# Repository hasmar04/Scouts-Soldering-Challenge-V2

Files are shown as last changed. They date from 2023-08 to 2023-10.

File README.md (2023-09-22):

# Scouts-Soldering-Challenge-V2

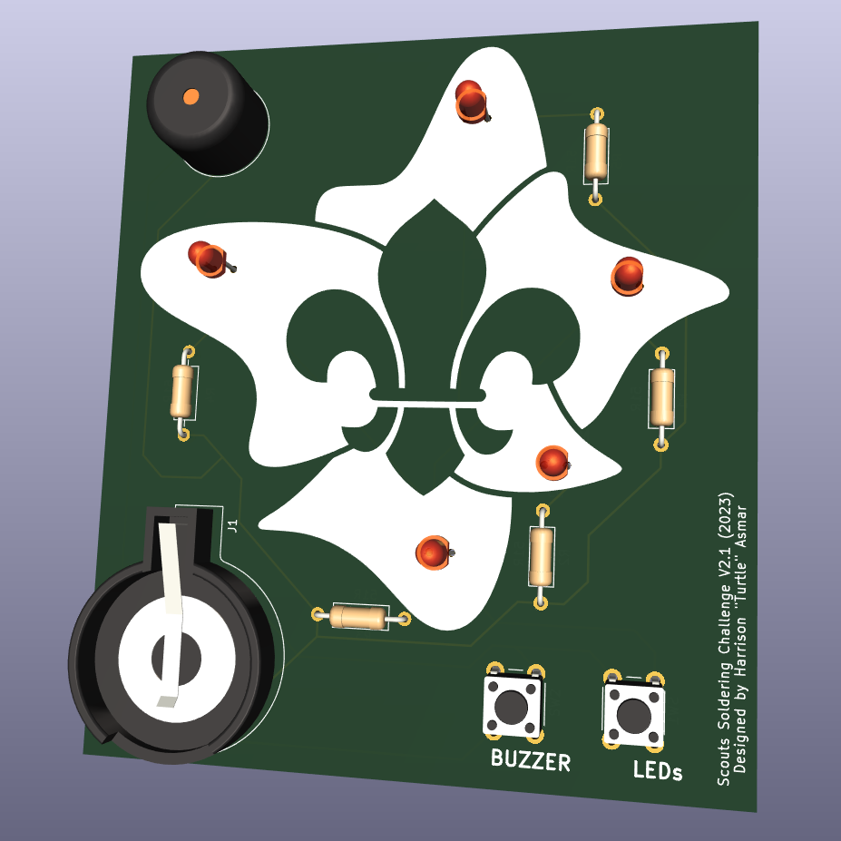
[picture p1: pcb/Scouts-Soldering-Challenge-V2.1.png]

 
A soldering challenge suitable for Scouts all the way to Rovers, without using an Arduino. 

As a member of the Australian Scouting movement, the logo has been used within this design for the purpose of promoting the movement, and to help the project to the target audience of Scouting members. 

For more information and/or assistance with implementing this challenge in your own Scout group, contact me at [246328@scoutsqld.com.au](mailto:246328@scoutsqld.com.au) 

### For more information on the Australian Scouting Movement, visit https://scouts.com.au/

## Components Required
- 1x PCB (see 'pcb' folder)
- 2x Red LED
- 1x Green LED
- 1x Yellow LED
- 1x Orange LED
- 5x 51 ohm resistor
- 1x 6x6mm push button
- 1x Buzzer
- 1x Battery Holder

More information can be found in the [Procurement Guide](/docs/Procurement%20Guide.md)

## Documentation
Documentation can be found in the [/docs](/docs) folder. This includes:
- Procurement Guide
- Assembly Guide

## Contributing
If there is anything that you think is missing from this repository, or you find an error, please [create an issue](</issues>) or fix it yourself and create a pull request.

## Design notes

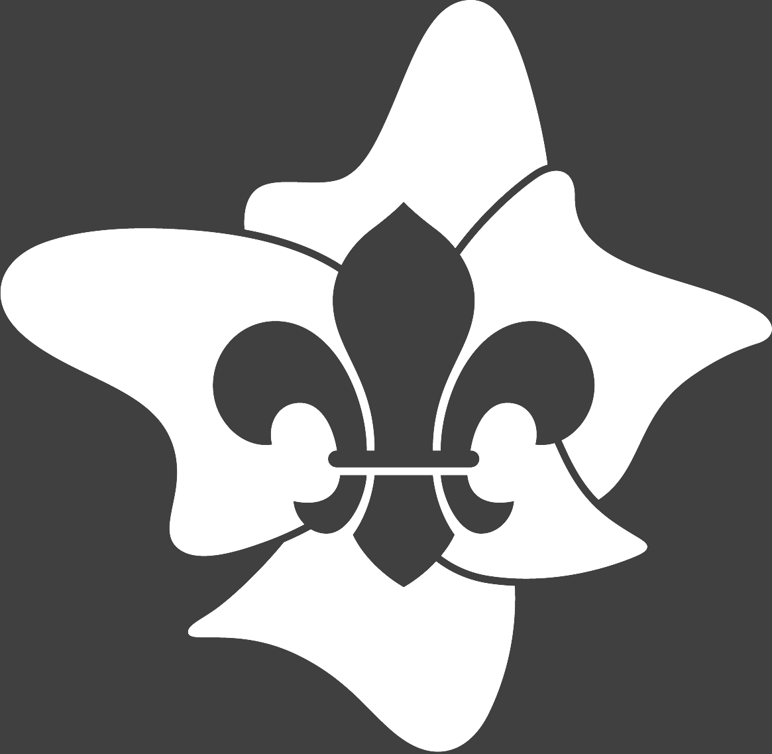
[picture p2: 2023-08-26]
Scouts Australia National White.png

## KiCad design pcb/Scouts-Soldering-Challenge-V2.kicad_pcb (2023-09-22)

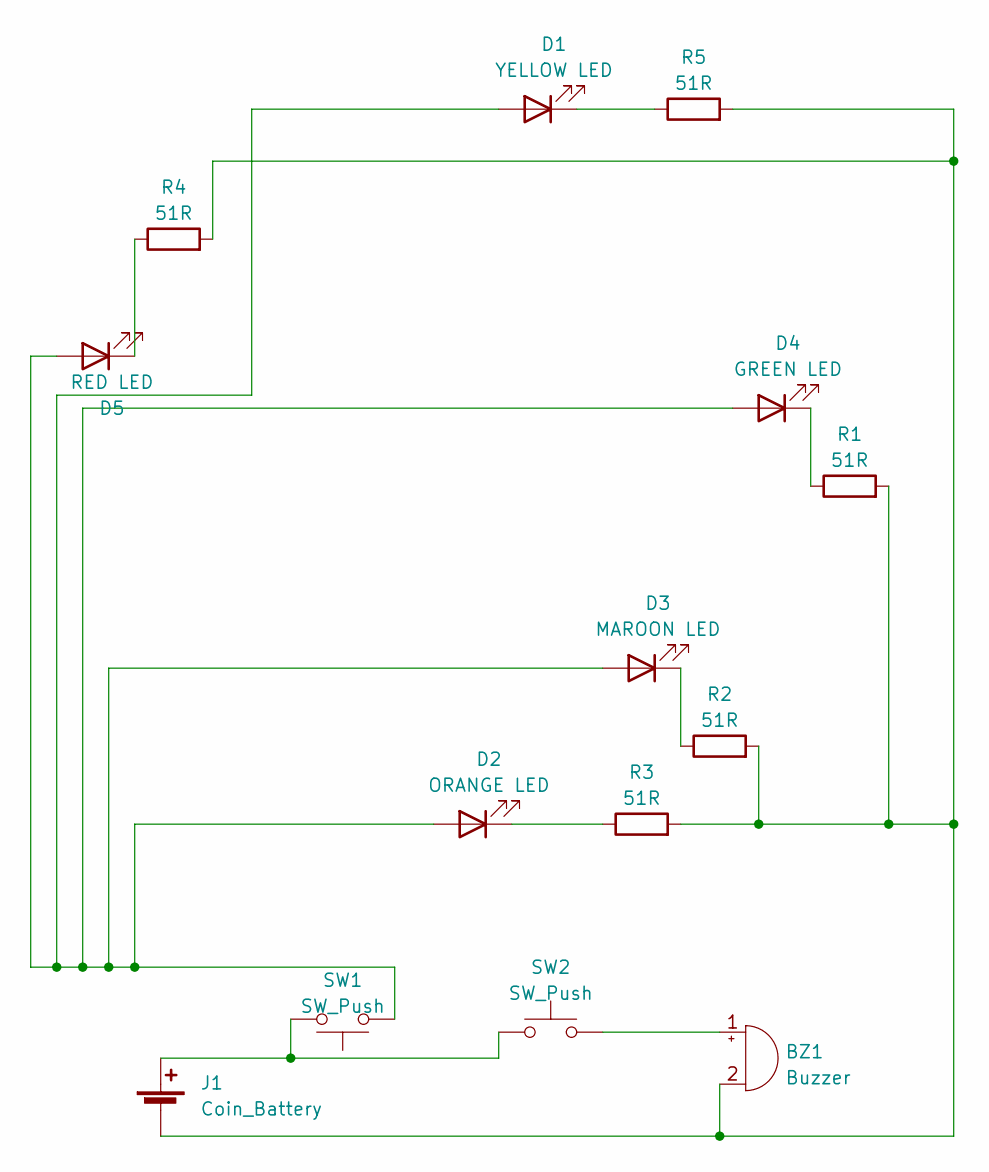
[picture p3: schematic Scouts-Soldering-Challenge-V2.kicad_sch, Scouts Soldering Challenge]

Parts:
BZ1: Buzzer; Buzzer_TDK_PS1240P02BT_D12.2mm_H6.5mm
D1: YELLOW LED; LED_D3.0mm
D2: ORANGE LED; LED_D3.0mm
D3: MAROON LED; LED_D3.0mm
D4: GREEN LED; LED_D3.0mm
D5: RED LED; LED_D3.0mm
J1: Coin_Battery; BatteryHolder_Keystone_103_1x20mm
R1, R2, R3, R4, R5: 51R; R_Axial_DIN0207_L6.3mm_D2.5mm_P10.16mm_Horizontal
SW1, SW2: SW_Push; SW_PUSH_6mm

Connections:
unnamed: BZ1.2 (+), J1.2 (-), R1.2, R2.2, R3.2, R4.2, R5.2
unnamed: BZ1.1 (-), SW2.2
unnamed: D1.2 (A), D2.2 (A), D3.2 (A), D4.2 (A), D5.2 (A), SW1.1
unnamed: D1.1 (K), R5.1
unnamed: D2.1 (K), R3.1
unnamed: D3.1 (K), R2.1
unnamed: D4.1 (K), R1.1
unnamed: D5.1 (K), R4.1
unnamed: J1.1 (+), SW1.2, SW2.1

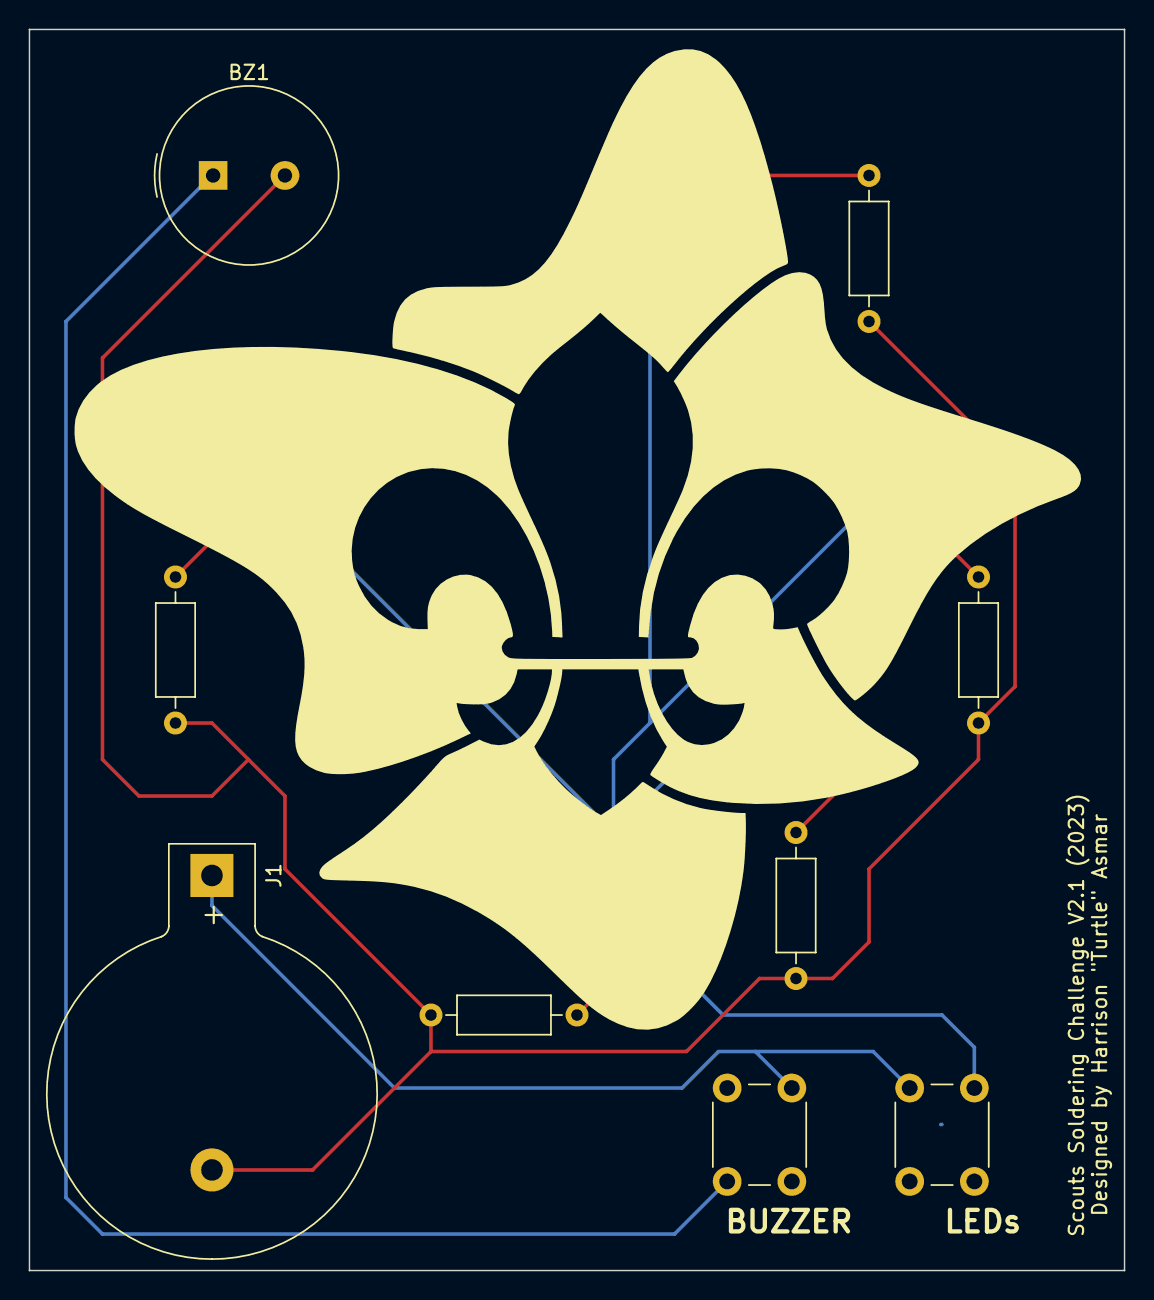
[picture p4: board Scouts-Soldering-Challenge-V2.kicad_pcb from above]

Board: 2 copper layers, 76.2 x 86.4 mm, 14 parts (0 on the bottom side), 9 nets.

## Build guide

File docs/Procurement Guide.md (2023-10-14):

 # Procurement Guide
For most people wanting to complete this project with a group, Element14 (au.element14.com) is the best place to acquire components from. They are based in Australia, and have pricing very similar to buying directly from suppliers overseas using a site such as Alibaba. 

Key characteristics that are needed when finding components:
- LEDs – through-hole, 3mm casing
- Push buttons – case dimensions of 6x6mm, 4 legs, through-hole, single-pole single-throw (SPST)
- Buzzer - Ensure the buzzer supports 3V, and the legs are 5mm (or close to) apart. Also ensure the buzzer you choose contains all the circuitry required to buzz, and does not need an external circuit. 
- Resistors – resistance of 51ohm, through-hole. Does not need to be more than 500mW or have a resistance tolerance of less than 1-2%. 
- Battery Holder - Make sure the diameter of the holder is 20mm if you want to use CR2032 or CR2025 batteries (both very common) and that the two legs on the holder are 20mm apart. Also, ensure the batteries you are using, if different to the ones listed, output 3V. 

Below is a list of parts that were available at the time of writing that would be suitable for this project:
- 3mm Red LED - https://au.element14.com/kingbright/l-1334surtk/led-3mm-red-630nm-red-transparent/dp/4062027
- 3mm Green LED - https://au.element14.com/multicomp/703-0087/led-green-3mm-572nm-standard/dp/2112096 
- 3mm Orange LED - https://au.element14.com/multicomp/mcl034at/led-3mm-32-orange/dp/1581126 
- 3mm Yellow LED - https://au.element14.com/lumex/ssl-lx3044yc/led-3mm-yellow-90mcd-585nm/dp/7605560 
- 6x6mm push button - https://au.element14.com/apem/mjtp1230/switch-tactile-spst-50ma-through/dp/4511189 
- Buzzer - https://www.jaycar.com.au/mini-piezo-buzzer-3-16vdc/p/AB3462
- 51ohm resistor - https://au.element14.com/multicomp-pro/mp006873/res-51r-0-25w-axial-metal-film/dp/3650040
- Battery Holder - https://au.element14.com/keystone/1066/battery-holder-1way/dp/133983901

If these parts are not available, there should be similar components available. Element14 also has the option to search for similar products based of characteristics like size and colour.

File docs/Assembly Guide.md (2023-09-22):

# Assembly Guide
## Before Proceeding
Ensure that you have all components listed in the [Procurement Guide](https://github.com/hasmar04/Scouts-Soldering-Challenge-V2/blob/main/docs/Procurement%20Guide.md), as well as a soldering iron and some solder. Lead-free solder is recommended, although it does require a higher temperature on the soldering iron. 
## Step 1: Sort Components Into Sets
This is recommended to be done before the night to make it easier to get the Scouts started on the project. Check out the [README](../README.md) for the list of required components. 
## Step 2: Start with the Resistors
It is always a good idea to start with the flattest components, which in this project are the resistors. There is no wrong orientation to install them. Poke the legs of the resistor through the holes, trying to make it as flat against the PCB as possible. Once in place, solder from the back side of the PCB and cut the excess legs off with sidecutters. 
## Step 3: Move onto the LEDs
The LEDs are the next tallest components, and require slighly more care than the resistors to install. Ensure the short leg of the LED goes to the square pad, putting it the other way around will not work. The legs can be bent to hold it in place. Once soldered in place, cut off extra leg length with sidecutters. For future reference, the square pad is typically for Ground, and the round pad for Power. The short leg of the LED is always for Ground, while the long leg is for Power. 
## Step 4: Insert and Solder the Buttons
The buttons have no polarity, and can go in either way. It should grab onto the PCB, making soldering it in place a breeze. Once soldered, and excess leg can be removed if desired. 
## Step 5: Solder the Battery Holder into Place
The battery holder only goes one way, so make sure to line it up with the outline on the PCB. Once soldered in place, cut off any extra leg length if necessary. 
## Step 6: Solder the Buzzer into Place
The tallest component is the buzzer, and it can only go one way. Make sure the positive side of the buzzer goes to the square pad. Solder in place, then cut off any extra leg length if required. 
## Step 7: Test!
Insert a battery and check that the lights turn on and the buzzer works when the buttons are pressed.

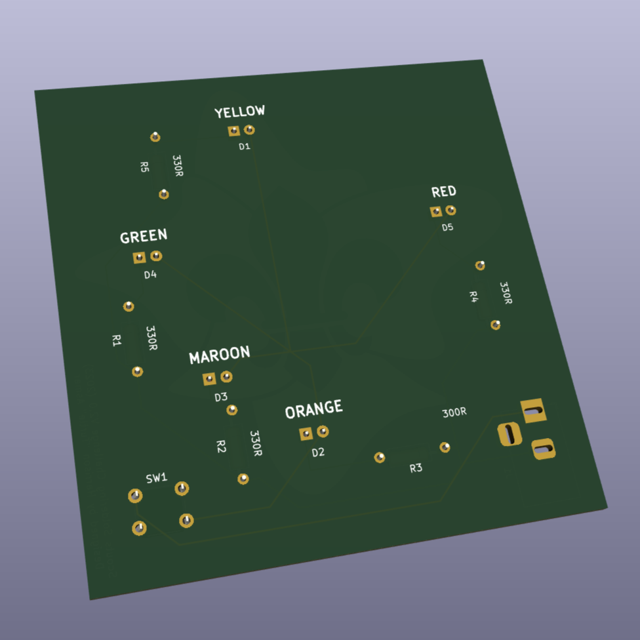
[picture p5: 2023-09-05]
pcb/Scouts-Soldering-Challenge-V2-Back.png

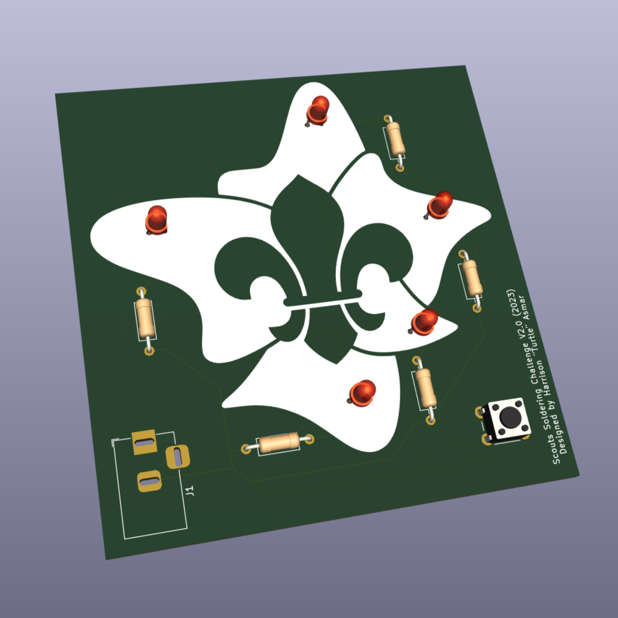
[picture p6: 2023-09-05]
pcb/Scouts-Soldering-Challenge-V2.png

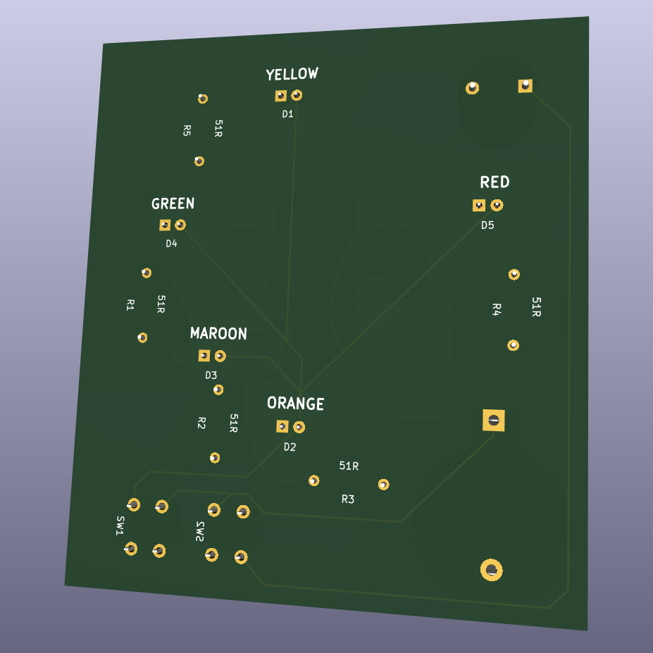
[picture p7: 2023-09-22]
pcb/Scouts-Soldering-Challenge-V2.1-Back.png

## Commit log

2023-08-26 Initial Repo Upload
    Includes new PCB design with aligned documentation. Also stripped all files that are not needed with the lack of Arduino.
    [Scouts-Soldering-Challenge-V2.kicad_pcb, Scouts-Soldering-Challenge-V2.kicad_sch]
2023-09-05 Removed lingering references to Arduino
    Made sure all references to Arduino are removed from the Assembly Guide
2023-09-05 Silkscreen version update to V2.0
    [Scouts-Soldering-Challenge-V2.kicad_pcb]
2023-09-05 Added renders of the board
2023-09-22 V2.1 of PCB and Schematic
    Complete overhall, adds a buzzer, replaces the barrel jack with a battery and changes the resistors to match. Also moves things around a lot.
    [Scouts-Soldering-Challenge-V2.kicad_pcb, Scouts-Soldering-Challenge-V2.kicad_sch]
2023-09-22 Update Assembly Guide.md
